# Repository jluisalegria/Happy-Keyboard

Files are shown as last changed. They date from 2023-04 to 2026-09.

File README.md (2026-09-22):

# Happy Keyboard
A 40% (47 keys) ortholinear keyboard built around the Raspberry Pi Pico and KMK firmware (powered by Python). A low-cost design with a sandwich case.

No reset button or unplugging is needed to update the keymap. Just edit `code.py` with any text editor, save, and you are done.
The code lives in a "flash drive" partition on the Pico, so you can edit the keymap on the go without DFU or any other dev tool.

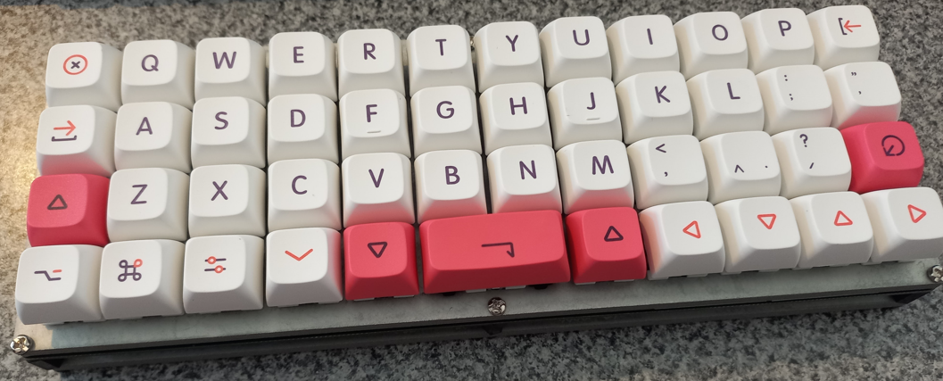
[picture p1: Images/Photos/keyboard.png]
Happy Keyboard


## Features
- Raspberry Pi Pico. Low cost and widely available.
- 2U space bar.
- Dual switch footprint. Supports direct soldering or Kailh hotswap sockets.
- SMD diodes.
- Programmable with [KMK Firmware](https://github.com/KMKfw/kmk_firmware "KMK Firmware"). Requires [CircuitPython](https://circuitpython.org/board/vcc_gnd_yd_rp2040/ "CircuitPython") to run.
- Optional RGB underglow, driven by a WS2812B strip.
- Assembled with M3 standoffs and screws.
- Designed in KiCad.

## Part List
- 1x RP2040 in the form of a Raspberry Pi Pico. I chose a [version with USB-C](https://es.aliexpress.com/item/1005003371056277.html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 "black version with USB C").
- 47x 1N4148 SOD-123 diodes.
- 47x [mechanical switches](https://es.aliexpress.com/item/1005002378701948.html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 "brown Outemu switches") (Cherry MX type).
- Keycaps. I chose white keycaps with a [pink theme](https://es.aliexpress.com/item/1005005120762702.html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 "pink theme").
- Optional: 24x WS2812B LEDs (a 5 V addressable strip) for the underglow. See [RGB Lighting](#rgb-lighting).
- Optional: [Kailh hotswap sockets](https://es.aliexpress.com/item/4001051840976.html?spm=a2g0o.cart.0.0.76d27a9dWyhGyQ&mp=1&gatewayAdapt=glo2esp "Kailh Hotswap sockets").

## Enclosure
- Aluminium or acrylic. Bottom: 3 mm. Plate: 1.5 mm.
- 6x M3x8 mm standoffs.
- 6x M3x6 mm screws.
- 6x M3x4 mm screws.

## Firmware
Two variants are included. Pick one and copy the contents of its folder to the
Pico's `CIRCUITPY` drive:

- **[Simple](Firmware/Simple)** - the plain keyboard, no lighting.
- **[With Led](Firmware/With%20Led)** - adds the RGB underglow, with the lighting
  controls mapped to the NUM layer.

Both share the same matrix and the same four layers.

## Layers
My keyboard layout is Spanish. These are my keycode layers.

Four layers come pre-programmed: QWERTY, LOWER, RAISE and NUM. To remap a key,
open `code.py` in any text editor and replace a keycode in the `keyboard.keymap`
matrix. Each row of the matrix is a physical row of the keyboard, read left to
right, so the positions match the images below:

```python
keyboard.keymap = [
    [  #QWERTY
        KC.ESC,  KC.Q,    KC.W,    ...   # top row, starting at the top-left key
```

Save the file and the keyboard reboots with the new keymap. The full list of
keycodes is in the [KMK documentation](https://github.com/KMKfw/kmk_firmware/blob/master/docs/en/keycodes.md "KMK keycodes").

### Layer 0
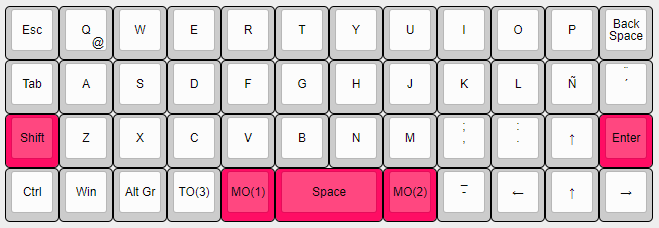
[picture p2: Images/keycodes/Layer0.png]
L0

### Layer 1
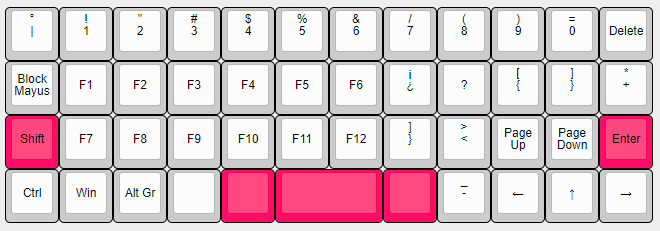
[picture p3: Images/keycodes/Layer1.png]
L1

### Layer 2
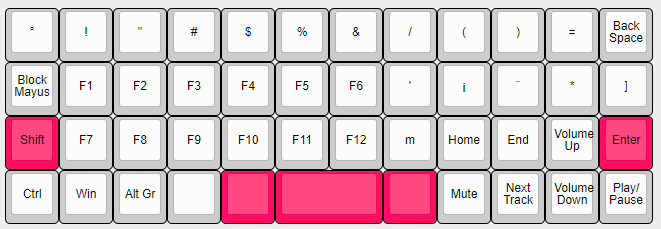
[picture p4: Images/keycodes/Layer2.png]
L2

### Layer 3
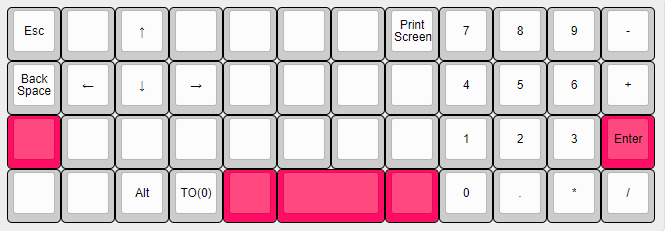
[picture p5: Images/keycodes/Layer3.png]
L3


## RGB Lighting
The **With Led** firmware drives a chain of **24 addressable LEDs** as underglow.

Use a 5 V **WS2812B** strip (also sold as "NeoPixel"), which is what the
`neopixel` driver behind KMK's RGB extension speaks. A 60 LED/m strip cut to 24
LEDs fits the board.

The strip sticks to the underside of the PCB with its own adhesive backing.
There is no LED connector on the board, so run three jumper wires and solder
them directly to the Pico:

| Strip | Pico |
| --- | --- |
| DIN (data in) | GP23 |
| +5V | VBUS (pin 40) |
| GND | any GND pin |

### How many LEDs can USB power?
A WS2812B draws up to 60 mA at full white, and the Pico itself needs around
50 mA. A USB 2.0 port supplies 500 mA in total, so the strip has roughly 400 mA
to work with once some headroom is left.

What matters is the LED count multiplied by the brightness, not either one
alone. These combinations all land near that 400 mA budget and are safe on any
port:

| LEDs | `val_limit` | Peak draw |
| --- | --- | --- |
| **24** | **64** (25%) | ~360 mA |
| 12 | 128 (50%) | ~360 mA |
| 7 | 255 (100%) | ~420 mA |

The shipped firmware uses the first row - the full 24 LEDs, capped at 25%
brightness. That is bright enough for underglow and leaves the port well inside
spec. `val_limit` is a hard ceiling: the brightness keys on the NUM layer cannot
push past it.

Going above this budget will not damage anything, but the port will current-limit
and the keyboard will disconnect or reboot mid-use. Raise `val_limit` only if you
power the board from something other than the USB host.

Both values live on one line in `code.py`, along with the data pin:

```python
rgb = RGB(pixel_pin=board.GP23, num_pixels=24, val_limit=64, ...)
```

The lighting controls (on/off, hue, saturation, brightness and the animation
modes) live on the NUM layer - see the Layer 3 image above.

## More Photos
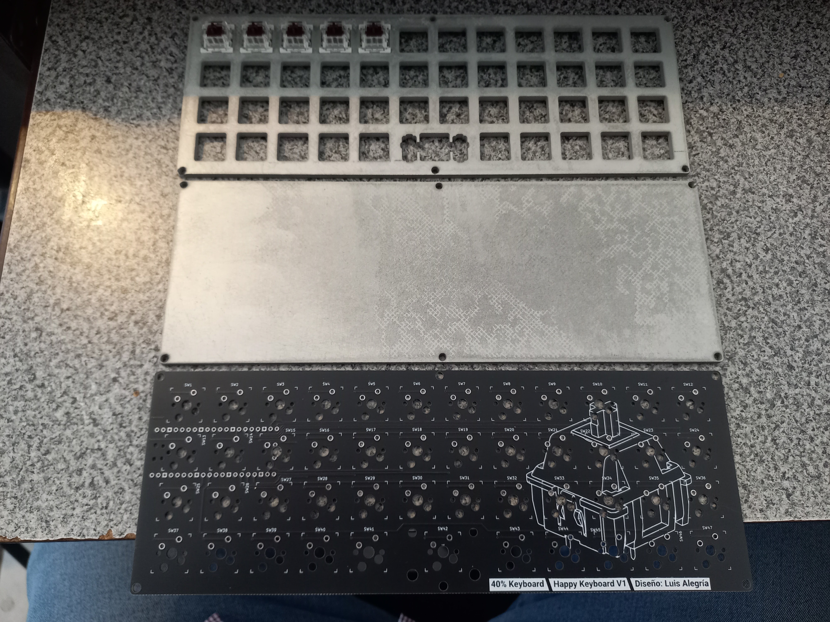
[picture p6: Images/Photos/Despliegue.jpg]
Exploded view

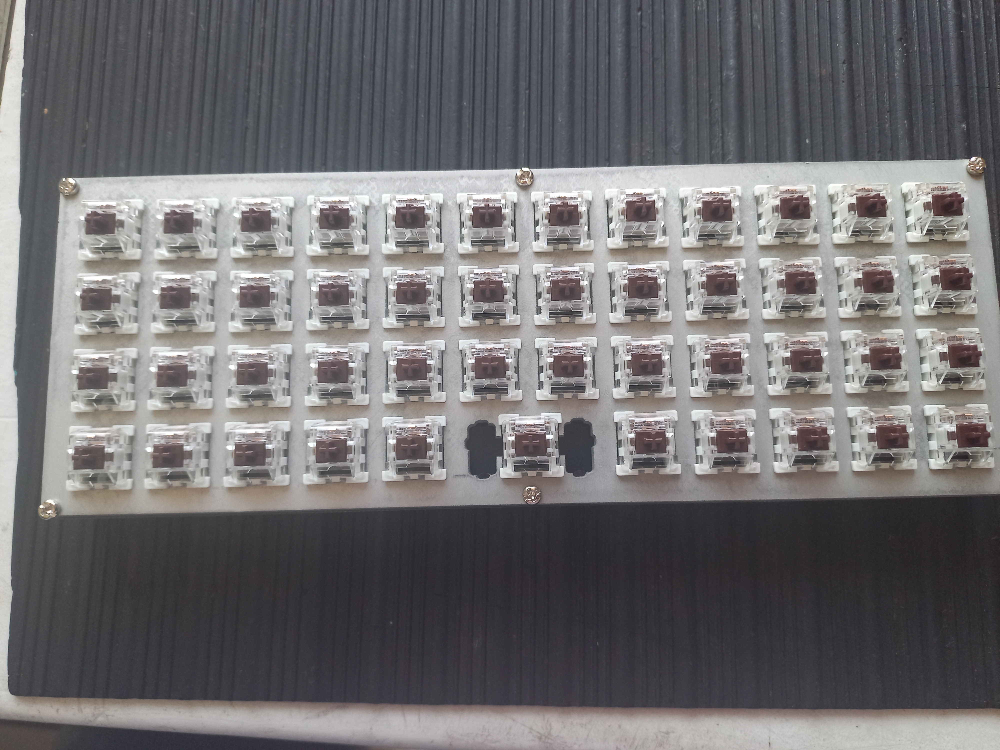
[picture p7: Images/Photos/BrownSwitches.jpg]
Switches

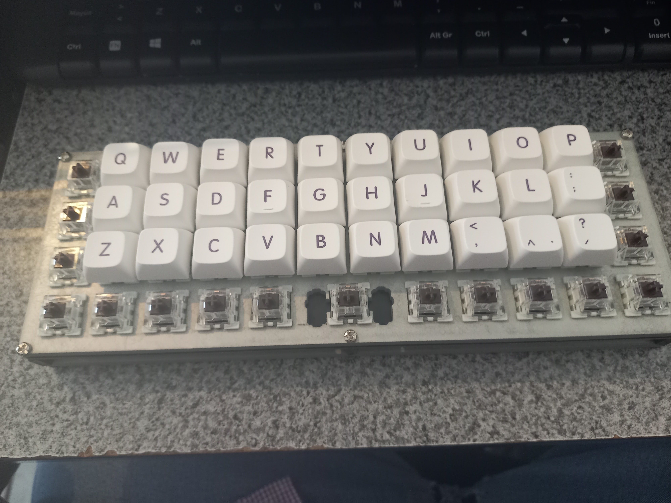
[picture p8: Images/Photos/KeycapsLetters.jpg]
Keycaps

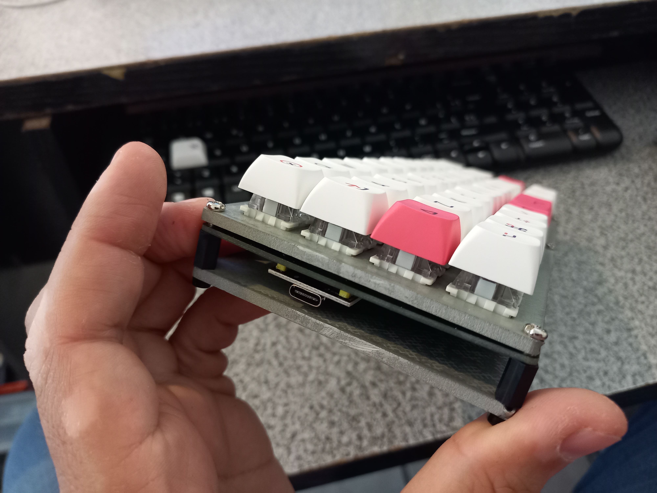
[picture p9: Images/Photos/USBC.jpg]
USB-C

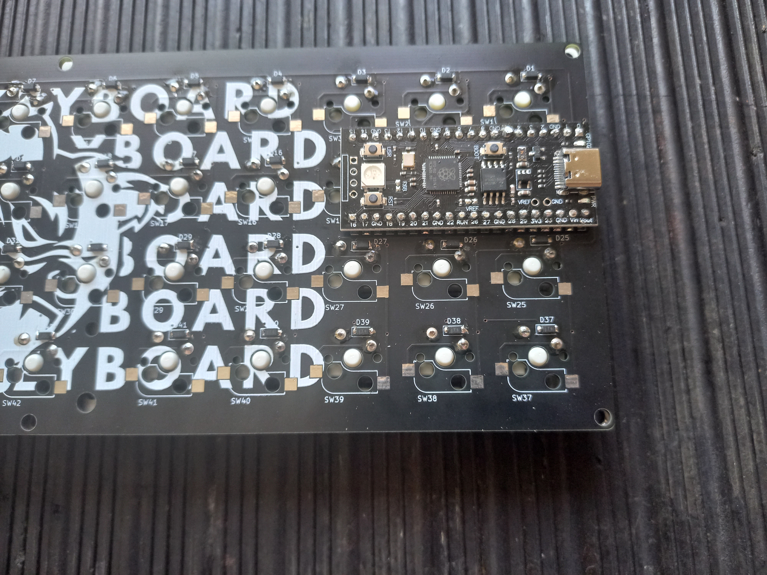
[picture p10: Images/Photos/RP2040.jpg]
RP2040

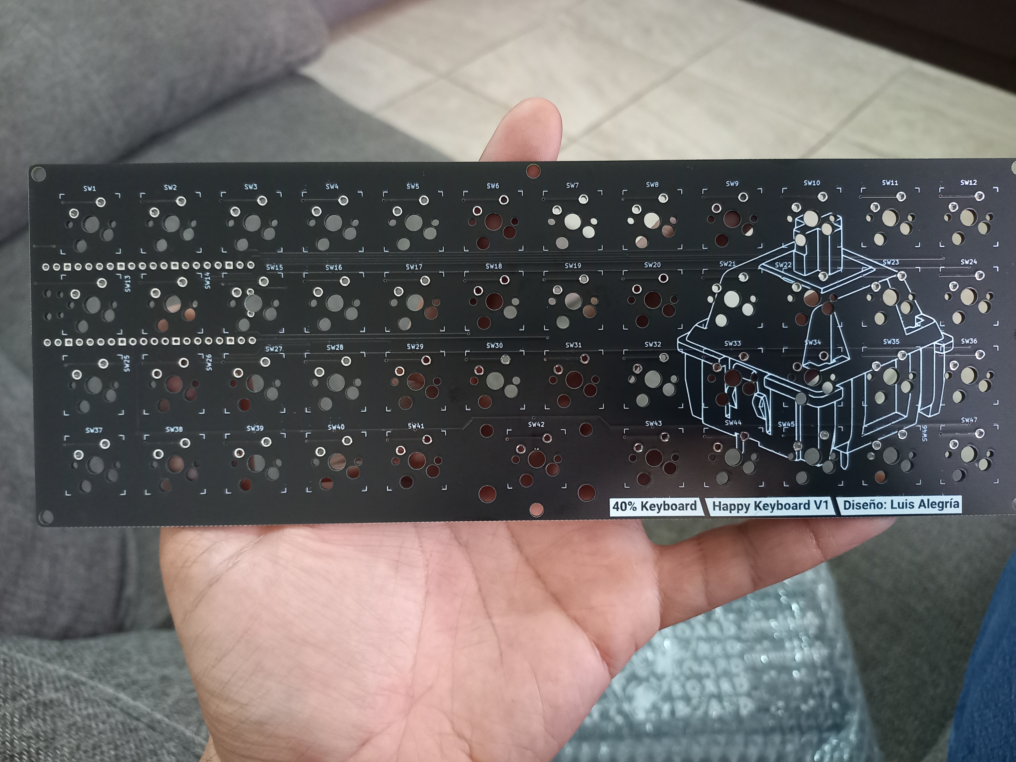
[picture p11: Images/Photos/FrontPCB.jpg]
Front PCB

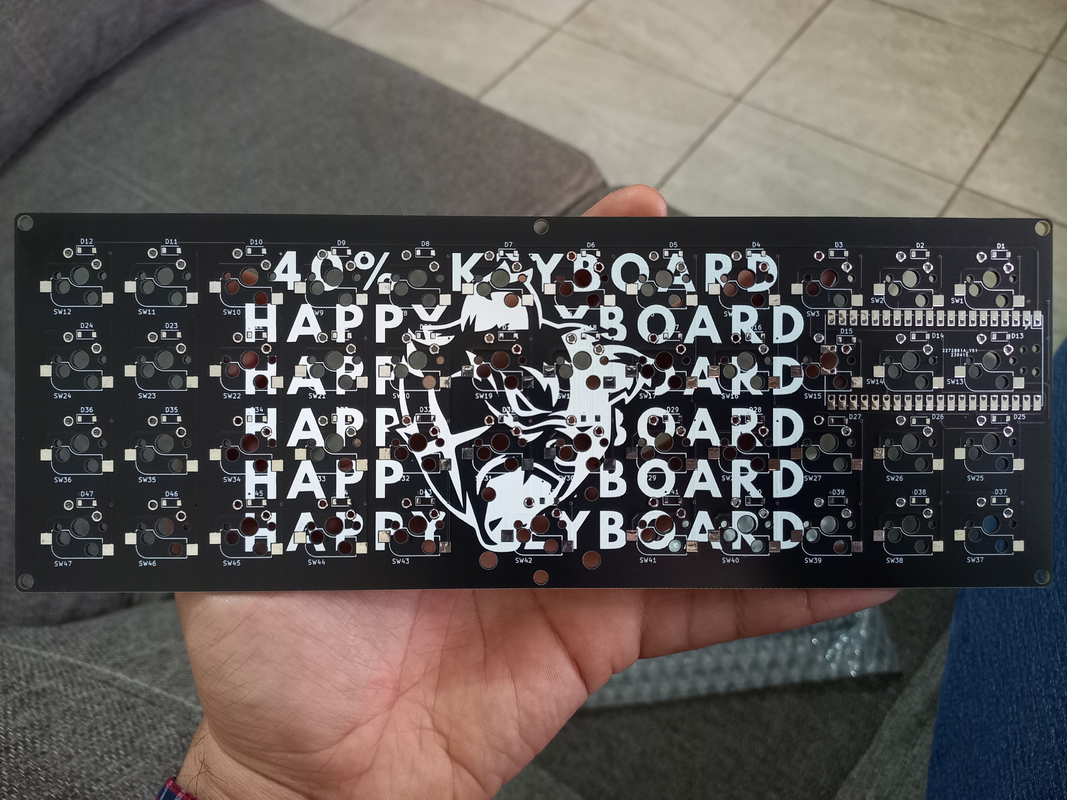
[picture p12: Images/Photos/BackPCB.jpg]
Back PCB


## Build your own [here](https://www.pcbway.com/project/shareproject/Happy_Keyboard_47_keys_Planck_Type_a725bc7f.html).

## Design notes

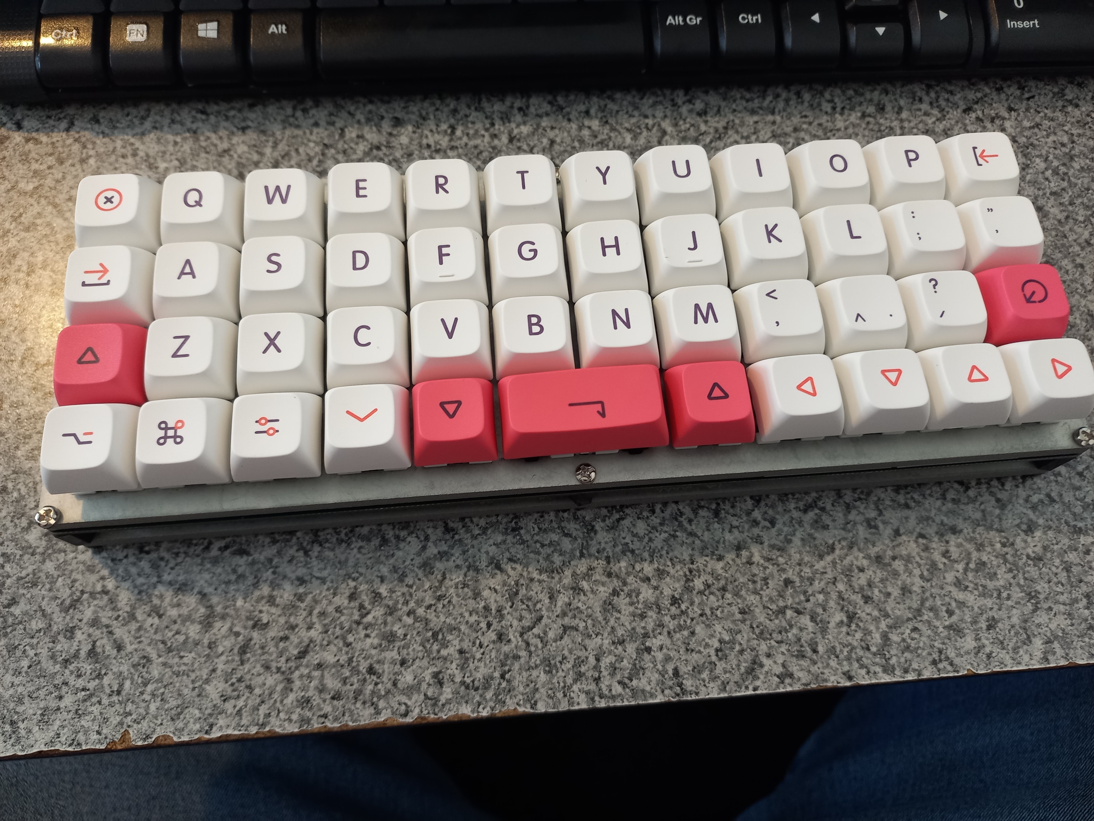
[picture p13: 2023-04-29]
Images/Photos/HappyKeeb.jpg

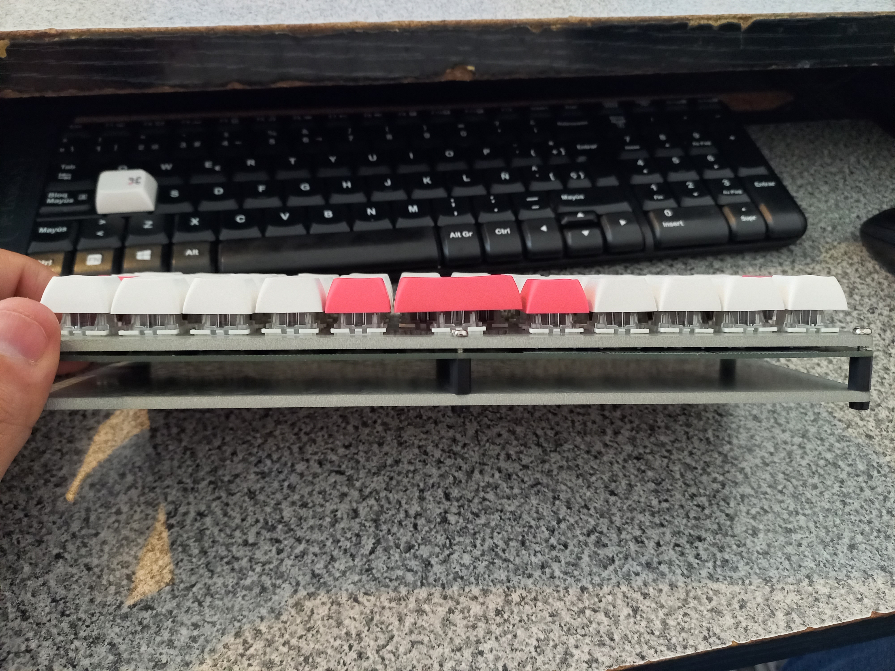
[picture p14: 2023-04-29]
Images/Photos/FrontView.jpg

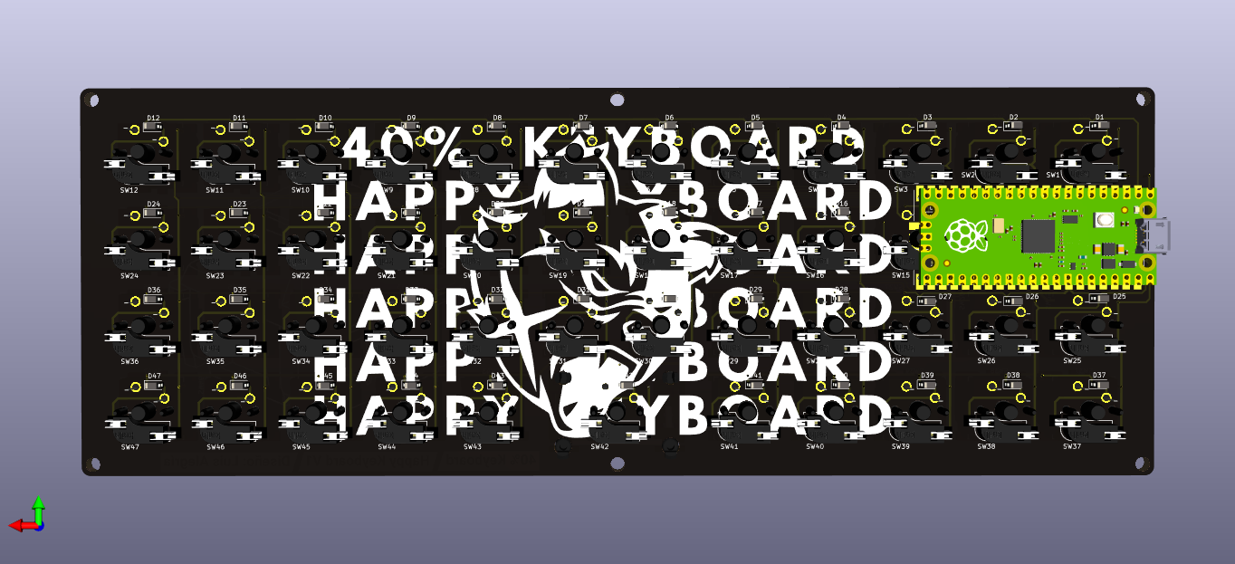
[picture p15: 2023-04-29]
Images/Render/Bottom.png

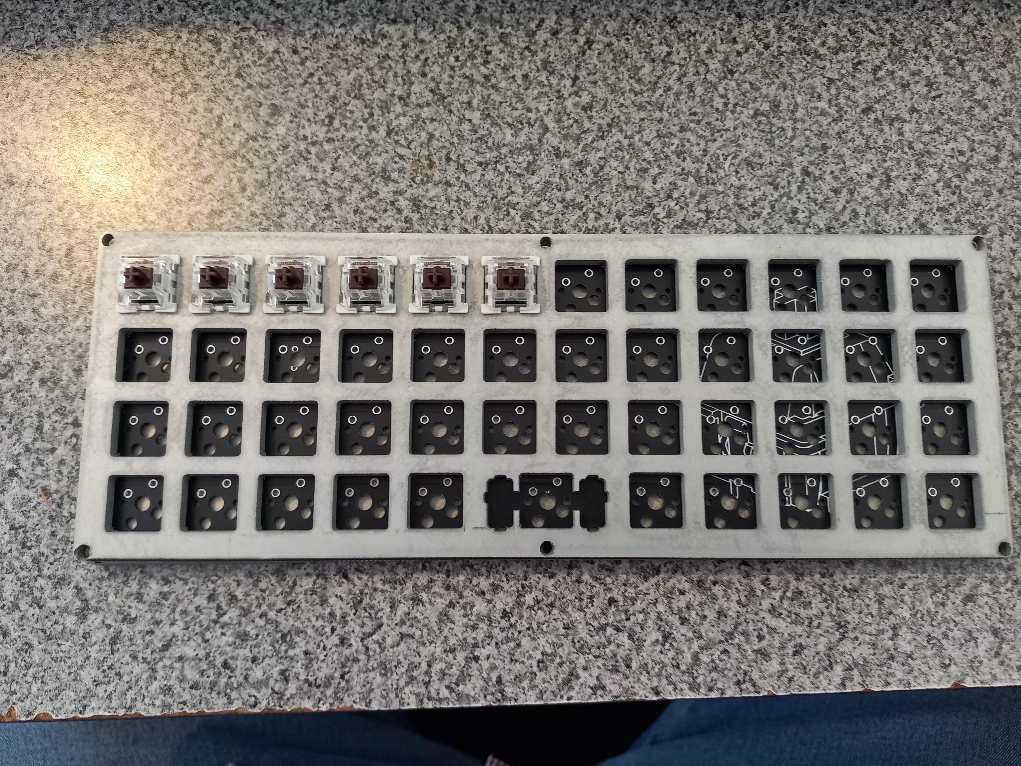
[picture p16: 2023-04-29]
Images/Photos/Mount1.jpg

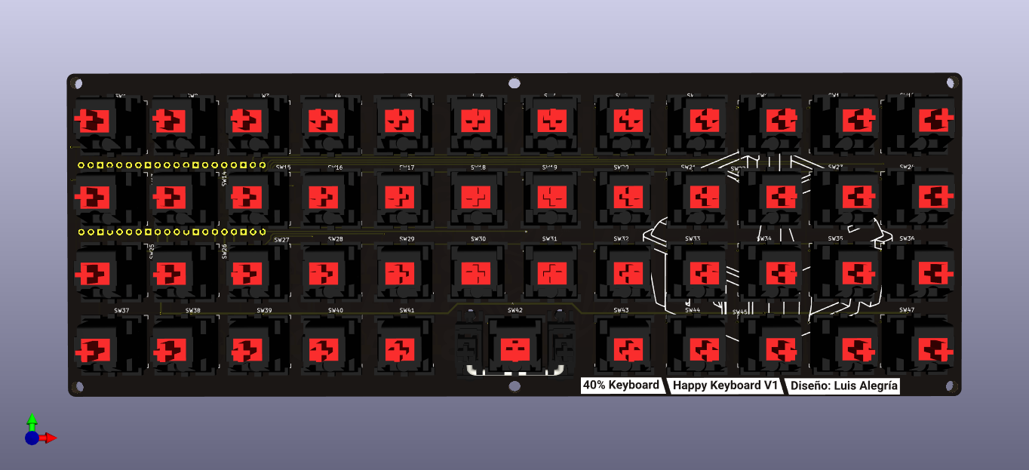
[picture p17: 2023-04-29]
Images/Render/Top.png

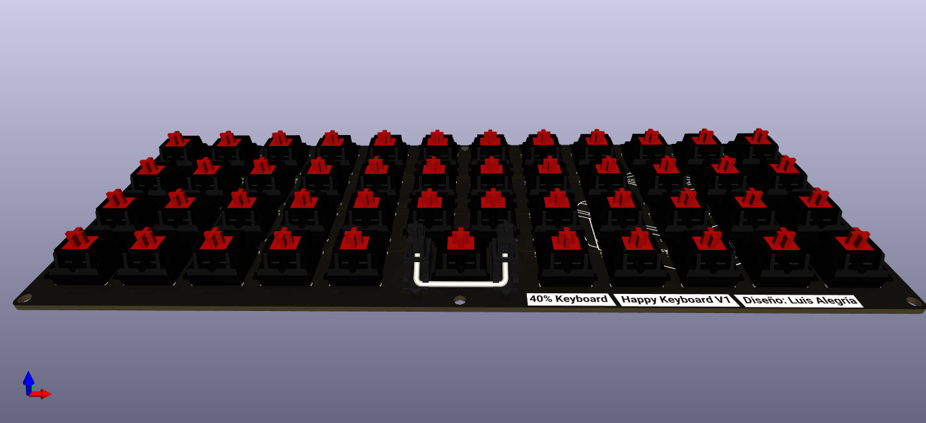
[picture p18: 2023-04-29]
Images/Render/Angle.png

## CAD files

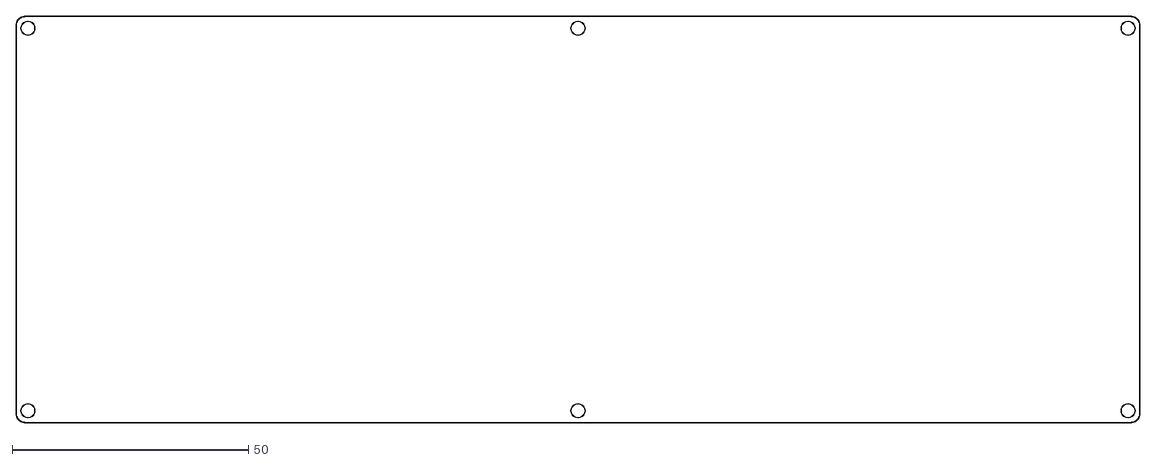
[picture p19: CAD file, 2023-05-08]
Enclosure/bottom.dxf
238.0 x 86.0

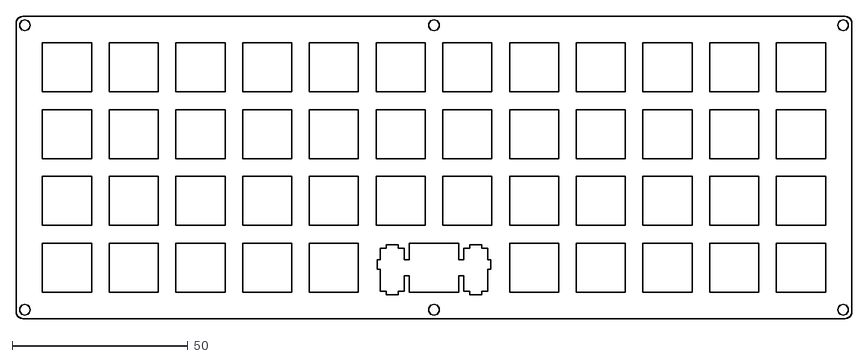
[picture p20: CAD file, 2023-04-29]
Enclosure/Plate.dxf
238.0 x 86.0

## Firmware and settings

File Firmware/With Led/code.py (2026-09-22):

print("Starting")

import board
import supervisor
import board
import digitalio
import storage
import usb_cdc
import usb_hid

from kmk.kmk_keyboard import KMKKeyboard
from kmk.extensions.rgb import RGB
from kmk.keys import KC
from kmk.scanners import DiodeOrientation
from kmk.modules.layers import Layers
from kmk.extensions.media_keys import MediaKeys


keyboard = KMKKeyboard()

# val_limit caps the brightness, and with it the current the strip draws.
# 24 LEDs at 25% brightness is about 360 mA, which stays inside the 500 mA
# a USB 2.0 port provides. Raise it only if the board is powered externally.
rgb = RGB(pixel_pin=board.GP23, num_pixels=24, val_limit=64, hue_default=252, sat_default=255, val_default=64, animation_speed=3)

keyboard.modules.append(Layers())

keyboard.extensions.append(MediaKeys())
keyboard.extensions = [rgb]

# Cleaner key names
_______ = KC.TRNS
XXXXXXX = KC.NO

LOWER = KC.MO(1)
RAISE = KC.MO(2)
NUM   = KC.MO(3)

RGB_TOG = KC.RGB_TOG
RGB_HUI = KC.RGB_HUI
RGB_HUD = KC.RGB_HUD
RGB_SAI = KC.RGB_SAI
RGB_SAD = KC.RGB_SAD
RGB_VAI = KC.RGB_VAI
RGB_VAD = KC.RGB_VAD
RGB_RAINB = KC.RGB_MODE_RAINBOW
RGB_BREAT = KC.RGB_MODE_BREATHE
RGB_M_BR = KC.RGB_MODE_BREATHE_RAINBOW
RGB_KNIGHT = KC.RGB_MODE_KNIGHT
RGB_SWIRL = KC.RGB_MODE_SWIRL
RGB_PLAIN = KC.RGB_MODE_PLAIN
RGB_ANI = KC.RGB_ANI
RGB_AND = KC.RGB_AND





# Cols
keyboard.col_pins = (board.GP27, board.GP10, board.GP20, board.GP19, board.GP18, board.GP17, board.GP16, board.GP15, board.GP14, board.GP13, board.GP12, board.GP11)
# Rows
keyboard.row_pins = (board.GP0, board.GP1, board.GP28, board.GP26)
# Diode Direction
keyboard.diode_orientation = DiodeOrientation.COL2ROW

# Keymap
keyboard.keymap = [
    [  #QWERTY
        KC.ESC,  KC.Q,    KC.W,    KC.E,    KC.R,    KC.T,    KC.Y,    KC.U,    KC.I,    KC.O,    KC.P,    KC.BSPC,
        KC.TAB,  KC.A,    KC.S,    KC.D,    KC.F,    KC.G,    KC.H,    KC.J,    KC.K,    KC.L,    KC.SCLN, KC.LBRC,
        KC.LSFT, KC.Z,    KC.X,    KC.C,    KC.V,    KC.B,    KC.N,    KC.M,    KC.COMM, KC.DOT,  KC.UP,   KC.ENT ,
        KC.LCTL, KC.LGUI, KC.RALT, NUM,     LOWER,   KC.SPC,  KC.SPC,  RAISE,   KC.SLSH, KC.LEFT, KC.DOWN, KC.RGHT
    ],
    [  #LOWER
        KC.GRV,  KC.N1,   KC.N2,   KC.N3,   KC.N4,   KC.N5,   KC.N6,   KC.N7,   KC.N8,   KC.N9,   KC.N0,   KC.DEL,
        KC.TAB, KC.F1,   KC.F2,   KC.F3,   KC.F4,   KC.F5,   KC.F6,   KC.EQL, KC.UNDS,  KC.QUOT, KC.BSLS, KC.RBRC,
        KC.CAPS, KC.F7,   KC.F8,   KC.F9,   KC.F10,  KC.F11,  KC.F12,  KC.NUHS, KC.NUBS, KC.PGUP, KC.PGDN, _______,
        KC.PSCR, XXXXXXX, KC.LALT, KC.TO(3), _______, _______, _______, _______, _______, XXXXXXX, XXXXXXX, XXXXXXX
    ],
    [  #RAISE
        KC.TILD, KC.EXLM, KC.AT,   KC.HASH, KC.DLR,  KC.PERC, KC.CIRC, KC.AMPR, KC.ASTR, KC.LPRN, KC.RPRN, KC.BSPC,
        KC.CAPS, KC.F1,   KC.F2,   KC.F3,   KC.F4,   KC.F5,   KC.F6,   KC.MINS, KC.PLUS, KC.LCBR, KC.RCBR, KC.PIPE,
        KC.LSFT, KC.F7,   KC.F8,   KC.F9,   KC.F10,  KC.F11,  KC.F12,  _______, KC.HOME, KC.END,  KC.VOLU, _______,
        _______, _______, KC.RALT, _______, _______, _______, _______, _______, KC.MUTE, KC.MNXT, KC.VOLD, KC.MPLY
    ],
    [  #NUM
        KC.ESC,  XXXXXXX, KC.UP,   RGB_TOG, RGB_HUI, RGB_VAI, RGB_SAI, KC.PSCR, KC.P7,  KC.P8,   KC.P9,   KC.BSPC,
        XXXXXXX, KC.LEFT, KC.DOWN, KC.RGHT, RGB_HUD, RGB_VAD, RGB_SAD, KC.SLSH, KC.P4,  KC.P5,   KC.P6,   KC.RBRC,
        XXXXXXX, XXXXXXX, XXXXXXX, RGB_PLAIN, RGB_RAINB, RGB_BREAT, RGB_M_BR, RGB_KNIGHT , KC.P1,  KC.P2,   KC.P3,   KC.ENT ,
        XXXXXXX, XXXXXXX, KC.LALT, KC.TO(0), RGB_AND, XXXXXXX, XXXXXXX, RGB_ANI, KC.P0,  KC.DOT,  KC.RCBR, KC.AMPR
    ]
]



if __name__ == '__main__':
    keyboard.go()

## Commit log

2023-05-08 Replace bottom.dxf. File was incorrect
    [bottom.dxf]
2023-08-21 Added firmware with led driver at bottom
2026-09-22 Improve README English wording
    Fix grammar, spelling and terminology throughout (hotswap sockets,
    CircuitPython, KiCad, space bar) and give the photo links descriptive
    alt text.
2026-09-22 Document firmware variants, keymap editing and RGB wiring
    Fix the dead Firmware/code.py link and describe the Simple and With Led
    variants, explain how to remap a key in the keymap matrix, and add an RGB
    Lighting section covering the WS2812B strip and how it wires to the Pico.
2026-09-22 Cap the LED brightness to the USB power budget, add .gitignore
    24 WS2812B at full white would draw 1.4 A, well past the 500 mA a USB 2.0
    port supplies. Set val_limit to 64 so the strip peaks near 360 mA, and
    document the LED count / brightness trade-off in the README.
    Also stop tracking files the tools regenerate: the macOS and CircuitPython
    leftovers on the CIRCUITPY drive, and KiCad's local session state.
